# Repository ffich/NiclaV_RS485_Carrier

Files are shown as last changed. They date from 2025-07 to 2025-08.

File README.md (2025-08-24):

# 🔌 NiclaV_RS485_Carrier

A **compact and robust carrier board** for the **Arduino Nicla Vision**, designed with **KiCad 9**, ideal for industrial and harsh environments where **RS485 communication** and **daisy-chain topology** are required.

---

## 📦 Introduction

The **NiclaV_RS485_Carrier** is a breakout board tailored for the **Arduino Nicla Vision**, adding RS485 communication and 24 V power handling capabilities. It simplifies integration into industrial or distributed IoT systems.

---

## 🔧 Key Features

- ⚡ **24 V Power Input**  
  Input via screw terminal, regulated by a **Buck converter** to safely power the Nicla.

- 🔄 **Integrated RS485 Transceiver**  
  Robust half-duplex serial communication, suited for industrial use.

- 🔗 **Dual Power/RS485 Connectors (IN/OUT)**  
  Enables **daisy-chain** connections between multiple devices.

- 🔥 **120 Ω Termination Resistor**  
  On-board line termination, selectable via jumper.

- 💡 **Status LEDs**  
  - **Power LED** for board status  
  - **User LED** controllable from the Nicla (for debug or signaling)

- 🖨️ **Designed with KiCad 9**  
  Fully open-source hardware project.

---

## 🧠 Use Cases

- 👁️‍🗨️ Distributed machine vision systems using RS485  
- 🏭 Industrial sensor nodes  
- 📷 Smart camera networks in the field  
- 📡 IoT endpoints for harsh environments

---

## 🧪 Project Status

🟢 **Ready for testing**  
Waiting for first prototypes, electrical and functional validation and RS485 bus communication testing.

---

## 📸 Preview



---

## ⚙️ TODO

- [ ] Validate RS485 over long-distance bus  
- [ ] Field test with 24 V industrial power  
- [ ] Add termination switch option  
- [ ] Design a 3D-printed enclosure

---

## 📬 Contact

For questions, feedback, or collaboration proposals, feel free to open an issue or reach out directly!

---

💙 Open-source project made with **Arduino** passion.

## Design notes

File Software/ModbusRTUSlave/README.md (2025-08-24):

# Modbus LED Controller Example

This project demonstrates how to implement a **Modbus RTU Slave** over **RS485** using the **Arduino Nicla Vision Carrier** with **MicroPython**.  
It allows controlling an LED (on **D3**) via Modbus RTU commands, providing feedback and debug information through the serial console.  

---

## Features
- **RS485 Half-Duplex** communication on `UART("LP1", 9600)`
- **Automatic TX/RX Direction Control** via **D0**
- **Modbus RTU Slave (ID=1)**:
  - **Function 0x05 – Write Single Coil** to turn LED ON/OFF
  - **Function 0x01 – Read Coils** to read LED state
- **Debug output** on serial: RX/TX frames, CRC check, LED state changes

---

## Hardware Setup
- **Arduino Nicla Vision** running MicroPython
- **RS485 Transceiver** connected to:
  - `D0` → DE/RE (direction control)
  - `LP1` TX/RX → RS485 transceiver UART pins
- **D3** connected to an LED (with current limiting resistor)
- **RS485 A/B lines** connected to RS485 bus with proper termination

---

## Files

- **rs485.py** – Low-level RS485 communication with automatic TX/RX direction switching  
- **modbus_slave.py** – Minimal Modbus RTU slave implementation (CRC16, coil handling)  
- **main.py** – Main loop: listens for Modbus requests, updates LED, sends responses  

---

## Usage
1. Upload `rs485.py`, `modbus_slave.py`, and `main.py` to your Nicla Vision.
2. Connect the Nicla to the RS485 bus.
3. Run the main application:

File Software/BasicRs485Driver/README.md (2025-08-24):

# RS485 LED Controller Example

This project demonstrates how to use **RS485 communication** with an **Arduino Nicla Vision** running **MicroPython**, controlling a **LED** via commands received over RS485.  

## Features
- **RS485 Half-Duplex Communication** using `UART("LP1", 9600)`
- **Automatic TX/RX Direction Control** on pin **D0**
- **LED Control** on pin **D3**:
  - Receives `led=1` → Turns LED ON, replies `LED ON`
  - Receives `led=0` → Turns LED OFF, replies `LED OFF`
- **Non-blocking receive with timeout** for responsive operation

---

## `rs485.py` – RS485 Communication Library

This module handles:
- UART initialization (`LP1`, 9600 baud)
- TX/RX direction control using **D0**
- Simple `send()` and `receive(timeout)` methods

### Key Methods:
- `send(data)`: Sends string/bytes over RS485, automatically switching to TX mode.
- `receive(timeout)`: Waits for incoming data for up to `timeout` milliseconds, returns received string or `None`.

---

## `main.py` – Application Logic

- Initializes:
  - `RS485` communication
  - LED output on **D3**
- Main loop:
  - Listens for incoming RS485 messages.
  - When `led=1` is received:
    - Turns LED ON
    - Sends `LED ON` feedback.
  - When `led=0` is received:
    - Turns LED OFF
    - Sends `LED OFF` feedback.

---

## Hardware Setup

- **Arduino Nicla Vision** mounted on the NiclaVCarrier
- **D0** → DE/RE pin of RS485 transceiver (direction control).
- **D3** → User LED
- **RS485 A/B lines** connected to RS485 network.

---

## Usage

1. Upload `rs485.py` and `main.py` to the Nicla Vision.
2. Connect to RS485 network.
3. Send `led=1` or `led=0` from another RS485 device to control the LED (in the project you'll find a Node-RED flow example, I used the wavesgare RS485 USB dongle for testing).

---

## Notes

- Ensure **proper RS485 termination resistors** if using long cables.
- Add a **delay (10–20ms)** between sending commands if multiple devices share the bus.

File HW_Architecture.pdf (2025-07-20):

Nicla Vision

RS485
Transceiver

24-5V Buck

INPUT
Conn

3V3 LDO

OUTPUT
Conn

User
LED

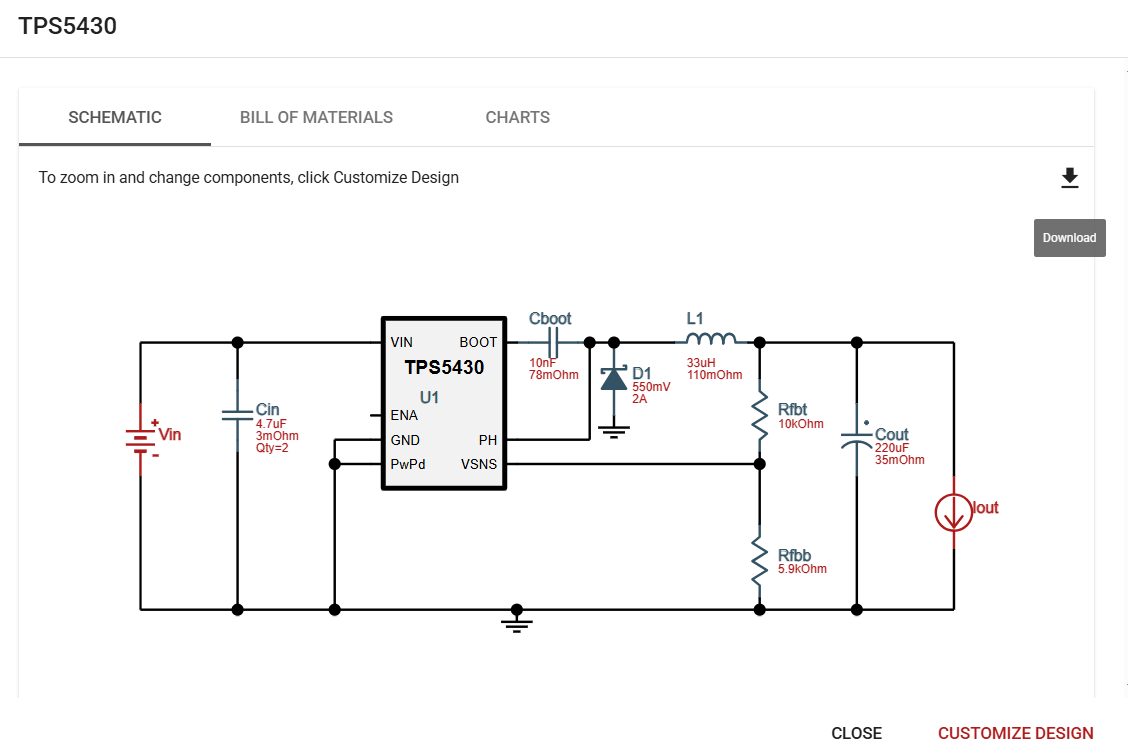
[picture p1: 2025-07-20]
NiclaVCarrier/Webench/2025-07-20_12h43_34.png

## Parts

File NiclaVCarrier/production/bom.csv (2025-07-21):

Designator | Footprint | Quantity | Value | LCSC Part #
A1 | Arduino_Nicla_Vision_Socket | 1 | Arduino_Nicla_Vision_Socket
C1 | 1206 | 1 | 10uF | C13585
C2 | 0402 | 1 | 10nF | C15195
C3 | CP_Elec_6.3x7.7 | 1 | 150uF | C7471880
C4 | 0603 | 1 | 1uF | C15849
C5 | 0402 | 1 | 470pF | C1537
C6 | 0603 | 1 | 10uF | C96446
CN1 | PhoenixContact_MSTBA_2,5_4-G-5,08_1x04_P5.08mm_Horizontal | 1 | Input | C192796
CN2 | PhoenixContact_MSTBA_2,5_4-G-5,08_1x04_P5.08mm_Horizontal | 1 | Output | C192796
D1 | D_SMA | 1 | D_Schottky | C412514
D2 | D_SMC | 1 | B560C-13-F | C85100
JP2 | PinHeader_2x04_P2.54mm_Vertical | 1 | Address | C225289
L1 | L_Bourns_SRP7028A_7.3x6.6mm | 1 | MWSA0624S-4R7MT | C408433
LD1, LD3 | 0603 | 2 | 3v3 | C2286
LD2 | 0603 | 1 | 5v | C2286
LD4 | 0603 | 1 | Tx | C2286
LD5 | 0603 | 1 | Rx | C2286
R1 | 0603 | 1 | 120 | C177328
R10, R11, R2, R5, R6 | 0402 | 5 | 1k | C140196
R3, R7, R8, R9 | 0805 | 4 | 10k | C17414
R4 | 0805 | 1 | 3.3k | C26010
U1 | TI_SO-PowerPAD-8_ThermalVias | 1 | TPS5430DDA | C9864
U2 | SOIC-8_3.9x4.9mm_P1.27mm | 1 | MAX3485EESA+T | C9943
U3 | SOT-23-5 | 1 | SPX3819M5-L-3-3 | C9055

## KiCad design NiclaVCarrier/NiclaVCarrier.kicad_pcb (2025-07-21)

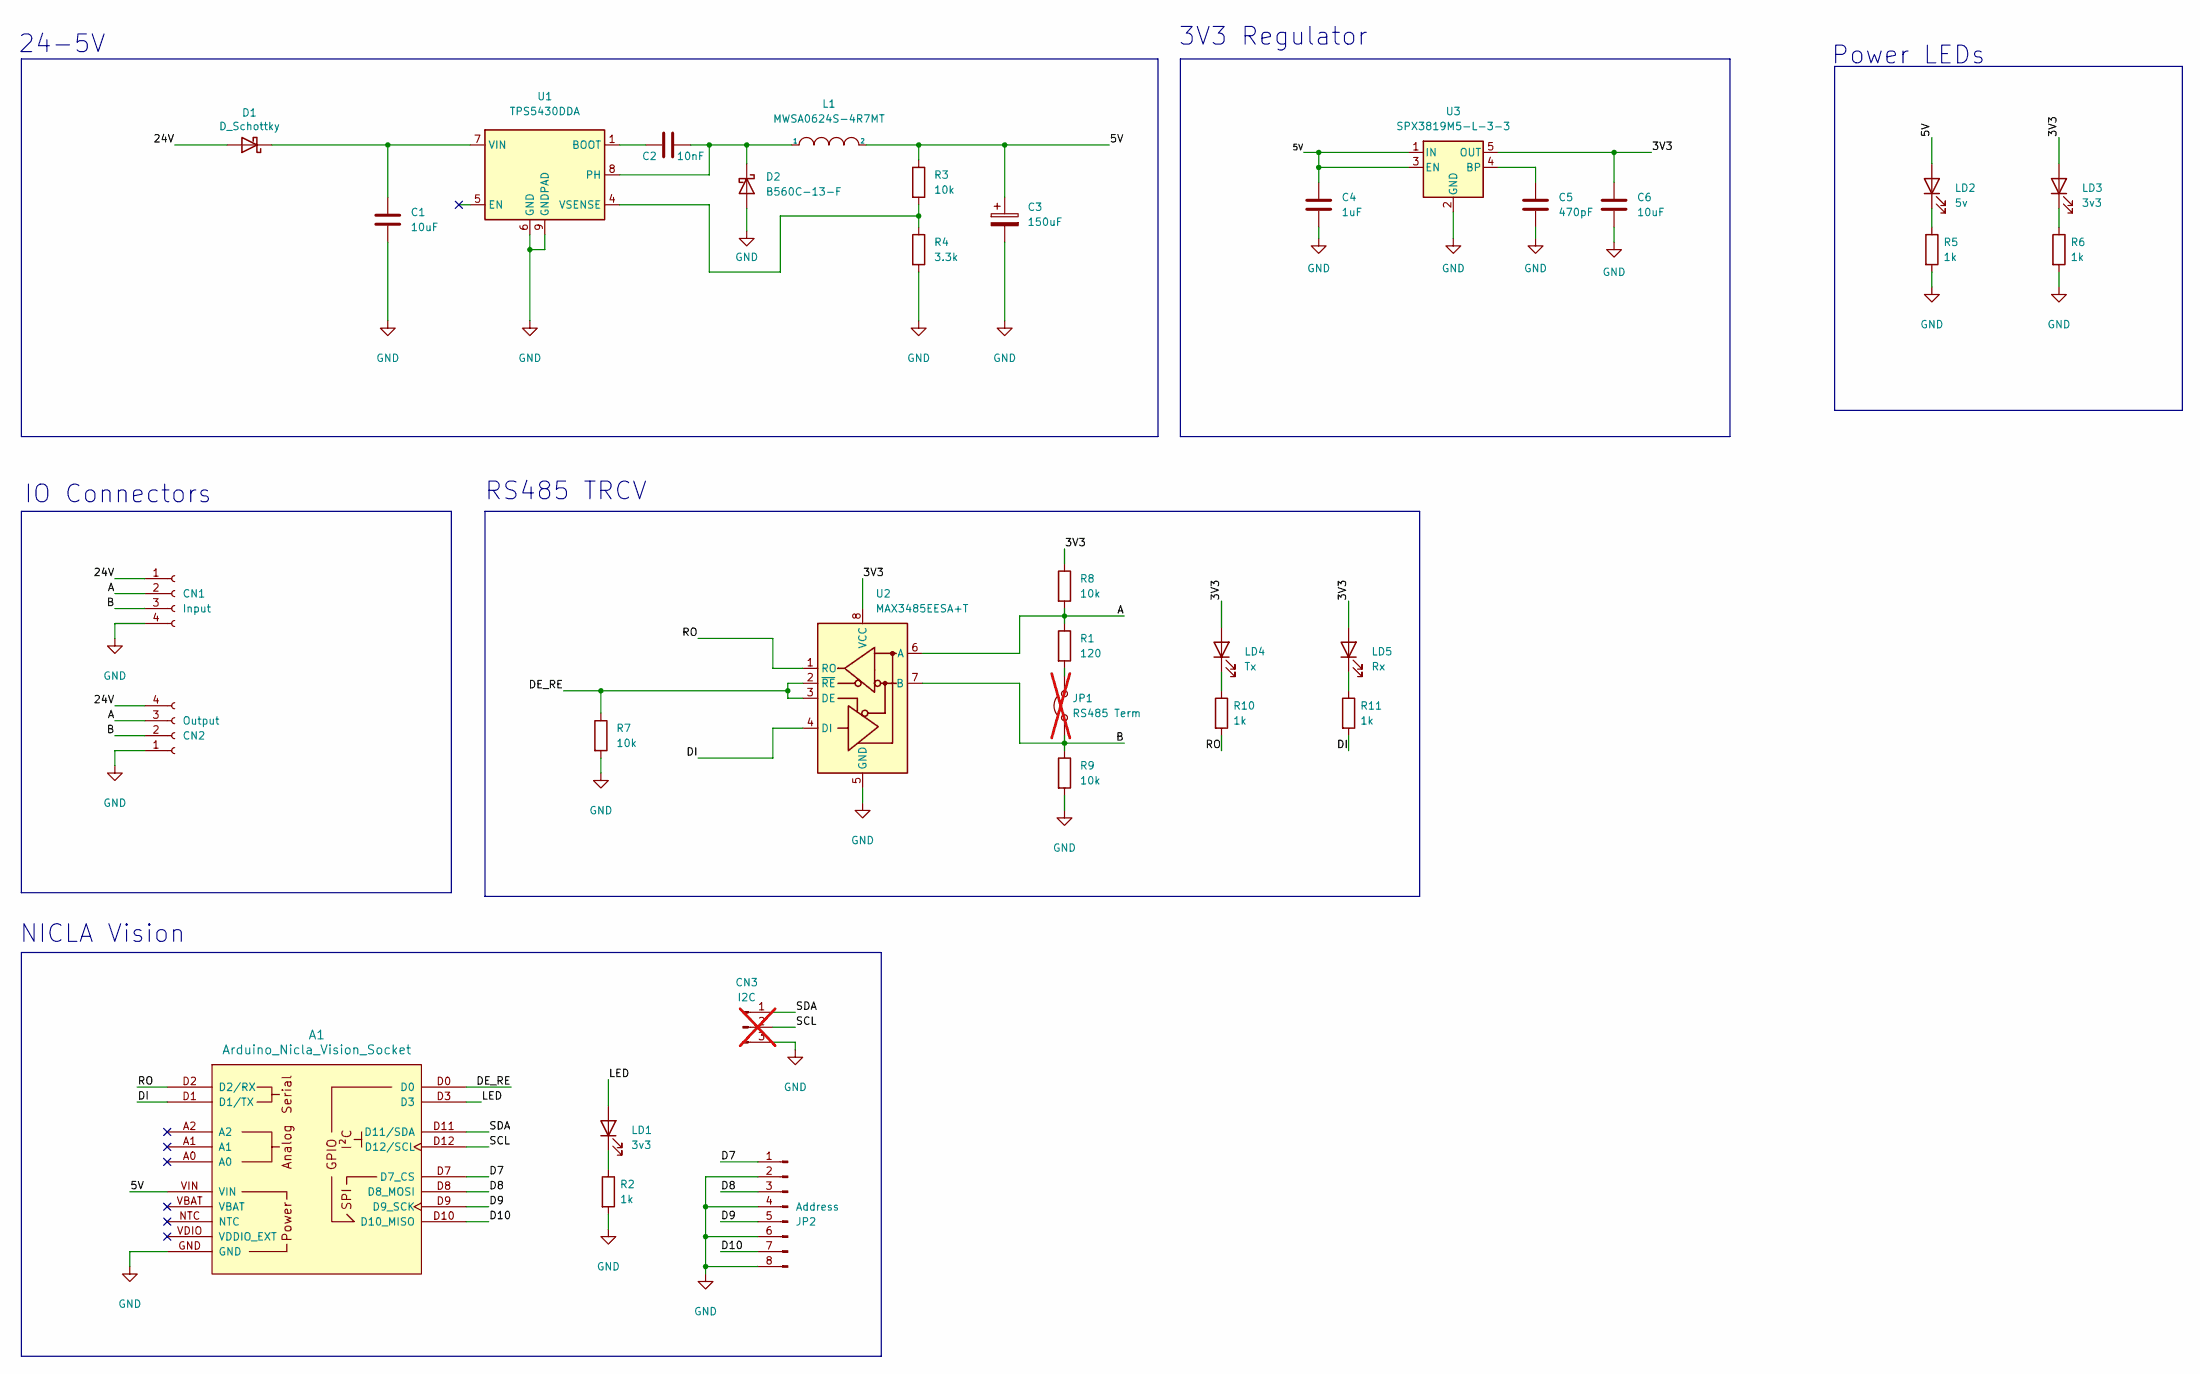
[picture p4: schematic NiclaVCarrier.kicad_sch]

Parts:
A1: Arduino_Nicla_Vision_Socket
C1: 10uF; C_1206_3216Metric; LCSC C13585
C2: 10nF; C_0402_1005Metric; LCSC C15195
C3: 150uF; CP_Elec_6.3x7.7; LCSC C7471880
C4: 1uF; C_0603_1608Metric; LCSC C15849
C5: 470pF; C_0402_1005Metric; LCSC C1537
C6: 10uF; C_0603_1608Metric; LCSC C96446
CN1: Input; PhoenixContact_MSTBA_2,5_4-G-5,08_1x04_P5.08mm_Horizontal; LCSC C192796
CN2: Output; PhoenixContact_MSTBA_2,5_4-G-5,08_1x04_P5.08mm_Horizontal; LCSC C192796
CN3: I2C; PinHeader_1x03_P2.54mm_Vertical; not fitted
D1: D_Schottky; D_SMA; LCSC C412514
D2: B560C-13-F; D_SMC; LCSC C85100
JP1: RS485 Term; PinHeader_1x02_P2.54mm_Vertical; not fitted
JP2: Address; PinHeader_2x04_P2.54mm_Vertical; LCSC C225289
L1: MWSA0624S-4R7MT; L_Bourns_SRP7028A_7.3x6.6mm; LCSC C408433
LD1, LD3: 3v3; LED_0603_1608Metric; LCSC C2286
LD2: 5v; LED_0603_1608Metric; LCSC C2286
LD4: Tx; LED_0603_1608Metric; LCSC C2286
LD5: Rx; LED_0603_1608Metric; LCSC C2286
R1: 120; R_0603_1608Metric; LCSC C177328
R2, R5, R6, R10, R11: 1k; R_0402_1005Metric; LCSC C140196
R3, R7, R8, R9: 10k; R_0805_2012Metric; LCSC C17414
R4: 3.3k; R_0805_2012Metric; LCSC C26010
U1: TPS5430DDA; TI_SO-PowerPAD-8_ThermalVias; LCSC C9864
U2: MAX3485EESA+T; SOIC-8_3.9x4.9mm_P1.27mm; LCSC C9943
U3: SPX3819M5-L-3-3; SOT-23-5; LCSC C9055

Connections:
/3V3: C6.1, LD3.2 (A), LD4.2 (A), LD5.2 (A), R8.1, U2.8 (VCC), U3.5 (OUT)
/5V: A1.VIN, C3.1, C4.1, L1.2, LD2.2 (A), R3.1, U3.1 (IN), U3.3 (EN)
/24V: CN1.1, CN2.4, D1.2 (A)
/A: CN1.2, CN2.3, R1.1, R8.2, U2.6 (A)
/B: CN1.3, CN2.2, JP1.1 (A), R9.1, U2.7 (B)
/D7: A1.D7 (D7_CS), JP2.1
/D8: A1.D8 (D8_MOSI), JP2.3
/D9: A1.D9 (D9_SCK), JP2.5
/D10: A1.D10 (D10_MISO), JP2.7
/DE_RE: A1.D0, R7.1, U2.2 (~RE), U2.3 (DE)
/DI: A1.D1 (D1/TX), R11.2, U2.4 (DI)
/LED: A1.D3, LD1.2 (A)
/RO: A1.D2 (D2/RX), R10.2, U2.1 (RO)
/SCL: A1.D12 (D12/SCL), CN3.2
/SDA: A1.D11 (D11/SDA), CN3.1
GND: A1.GND, C1.2, C3.2, C4.2, C5.2, C6.2, CN1.4, CN2.1, CN3.3, D2.2 (A), JP2.2, JP2.4, JP2.6, JP2.8, R2.2, R4.2, R5.2, R6.2, R7.2, R9.2, U1.6 (GND), U1.9 (GNDPAD), U2.5 (GND), U3.2 (GND)
unnamed: C1.1, D1.1 (K), U1.7 (VIN)
unnamed: C2.1, D2.1 (K), L1.1, U1.8 (PH)
unnamed: JP1.2 (B), R1.2
unnamed: LD1.1 (K), R2.1
unnamed: LD2.1 (K), R5.1
unnamed: LD3.1 (K), R6.1
unnamed: LD4.1 (K), R10.1
unnamed: LD5.1 (K), R11.1
unnamed: C2.2, U1.1 (BOOT)
unnamed: R3.2, R4.1, U1.4 (VSENSE)
unnamed: C5.1, U3.4 (BP)

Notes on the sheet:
RS485 TRCV
3V3 Regulator
NICLA Vision
Power LEDs
24-5V
IO Connectors

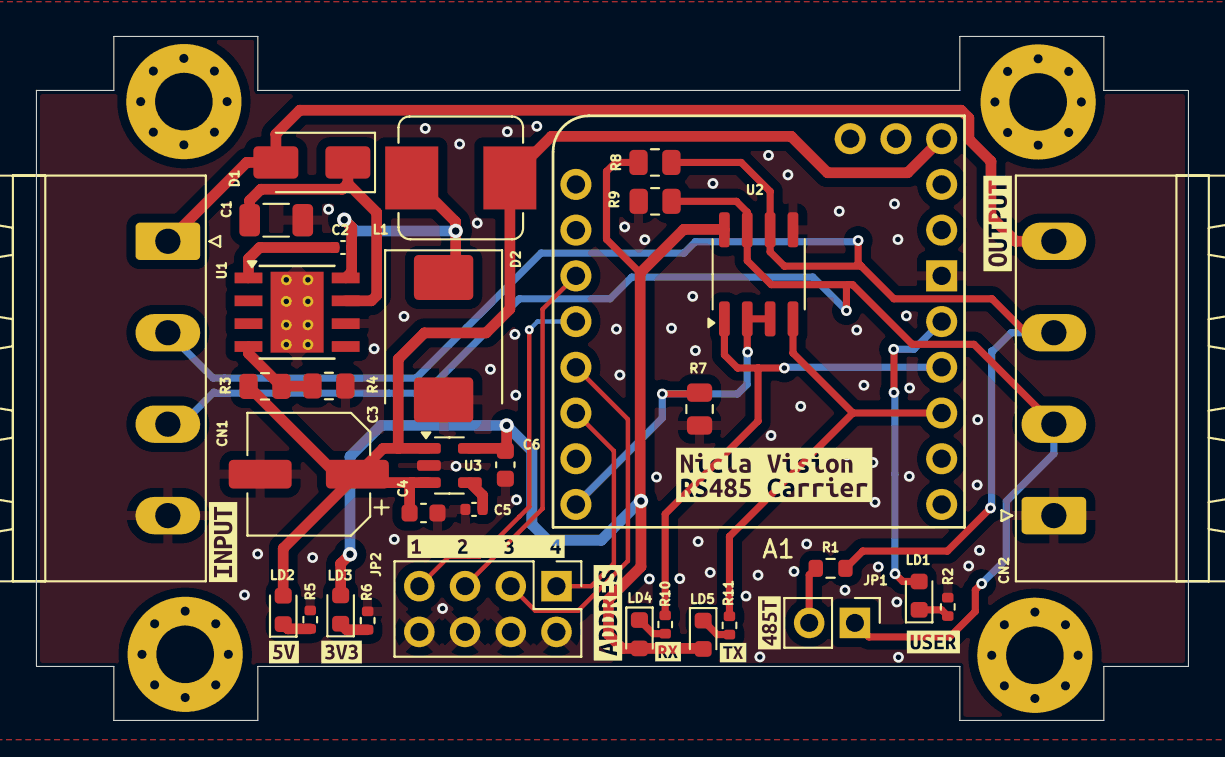
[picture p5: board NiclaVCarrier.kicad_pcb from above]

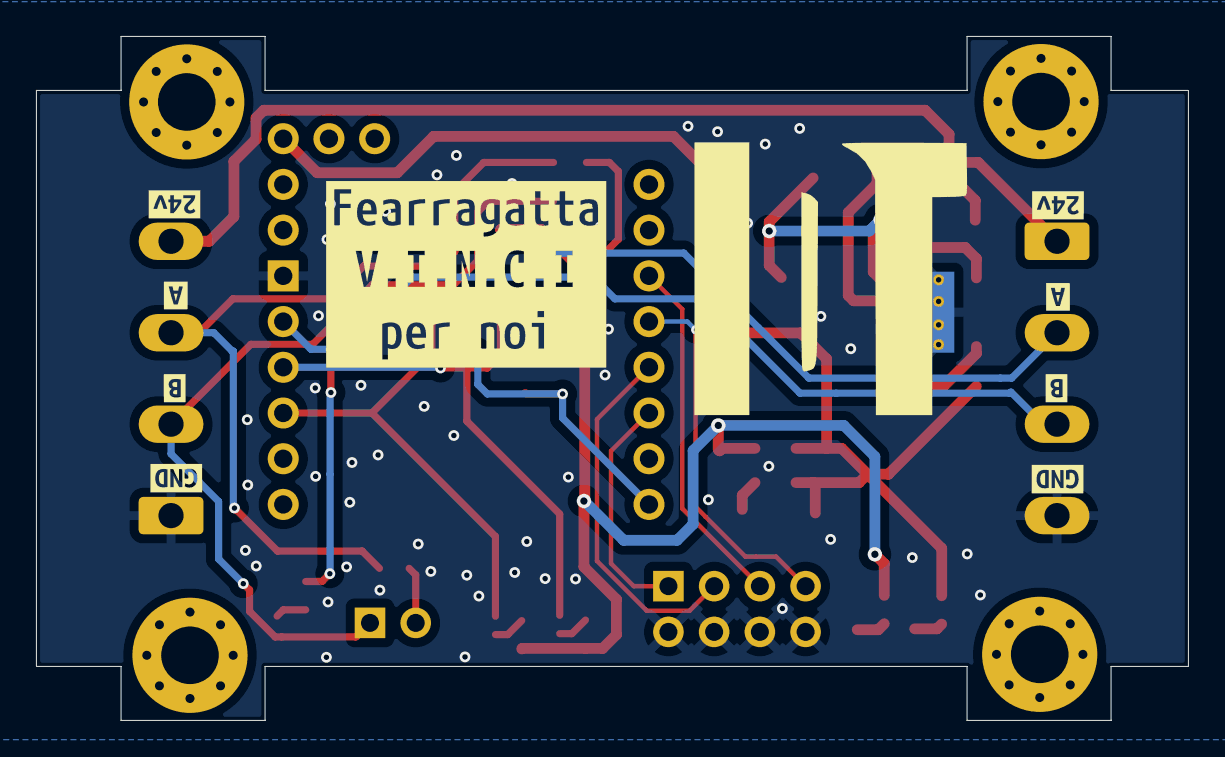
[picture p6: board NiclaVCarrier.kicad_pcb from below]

Board: 4 copper layers, 64.0 x 38.0 mm, 53 parts (9 on the bottom side), 25 nets.

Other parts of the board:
kibuzzard-687D11A9: G***; kibuzzard-687D11A9
kibuzzard-687D11CA: G***; kibuzzard-687D11CA
kibuzzard-687D13F1: G***; kibuzzard-687D13F1
kibuzzard-687D22F4: G***; kibuzzard-687D22F4
kibuzzard-687D118B: G***; kibuzzard-687D118B
kibuzzard-687D122C, kibuzzard-687D122C#2: G***; kibuzzard-687D122C
kibuzzard-687D124A, kibuzzard-687D124A#2: G***; kibuzzard-687D124A
kibuzzard-687D125B, kibuzzard-687D125B#2: G***; kibuzzard-687D125B
kibuzzard-687D131B: G***; kibuzzard-687D131B
kibuzzard-687D1205: G***; kibuzzard-687D1205
kibuzzard-687D1264, kibuzzard-687D1264#2: G***; kibuzzard-687D1264
kibuzzard-687D1379: G***; kibuzzard-687D1379
kibuzzard-687D1424: G***; kibuzzard-687D1424
kibuzzard-687E9AA8: G***; kibuzzard-687E9AA8
kibuzzard-687E9ABC: G***; kibuzzard-687E9ABC
kibuzzard-687E9791: G***; kibuzzard-687E9791

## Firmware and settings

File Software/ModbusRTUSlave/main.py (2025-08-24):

import time
from rs485 import RS485
from modbus_slave import ModbusRTUSlave

rs485 = RS485()
slave = ModbusRTUSlave(rs485, slave_id=1)

print("Modbus RTU Slave started (ID=1). Listening...")

while True:
    frame = rs485.receive(500)
    if frame:
        response = slave.handle_request(frame)
        if response:
            rs485.send(response)
    time.sleep_ms(10)

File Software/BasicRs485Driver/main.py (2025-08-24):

from machine import Pin
import time
from rs485 import RS485

# Initialize RS485 communication
rs485 = RS485()

# Initialize LED on D3 (LOW = off, HIGH = on)
led = Pin("D3", Pin.OUT)
led.value(0)

print("RS485 LED Controller started.")

while True:
    # Wait for incoming data
    msg = rs485.receive(500)  # Poll
    
    if msg:
        msg = msg.strip()
        print("Received:", msg)
        
        if msg == "led=1":
            led.value(1)
            rs485.send("LED ON\n")
            print("LED turned ON")
        
        elif msg == "led=0":
            led.value(0)
            rs485.send("LED OFF\n")
            print("LED turned OFF")
    
    # Optional: add a short delay to reduce CPU load
    time.sleep_ms(10)

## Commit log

2025-07-21 Updated design
    [NiclaVCarrier.kicad_pcb, NiclaVCarrier.kicad_sch, bom.csv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]
2025-08-24 Added basic driver support
